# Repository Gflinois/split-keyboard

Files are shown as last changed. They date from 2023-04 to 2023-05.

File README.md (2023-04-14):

# Split-keyboard

This Git project contains everything that is needed for the construction of split 60 % keyboard. The layout used is a custom one (see layout) base on international qwerty. The project include:

- pcb files of a proof of concept with 4 switches
- pcb files of each of the keyboard sides
- a shopping list for all needed components
- cad, stl and gcode for the case files (gcode for an ender 3 with a probe)
- cad, stl and gcode for the keycaps (gcode for an anycubic proton)
- the driver module to use it on linux
- the driver module to use it on windows

## Layout
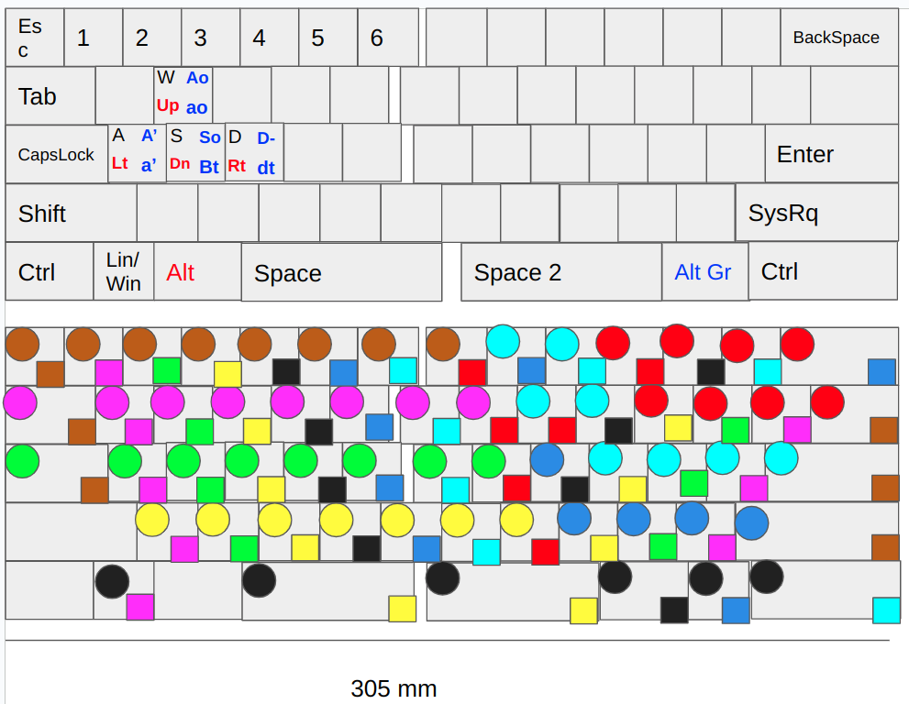
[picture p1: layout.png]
big L mec
 

## Electronic specifiactions

This keyboard is a usb-c teather based one (no battey nor wireless connection provided yet). It is powered by an Atmega 328P stolen on an old arduino nano.

## Contribution

Contributions to this Git project are welcome! Please submit pull requests to the `dev` branch and include a detailed description of your changes.

## License

This project is licensed under the MIT License. See the `LICENSE` file for details.

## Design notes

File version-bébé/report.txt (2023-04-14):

Info: Processing symbol 'R1:Resistor_SMD:R_0805_2012Metric'.
Info: Processing symbol 'C1:Capacitor_SMD:C_0805_2012Metric'.
Info: Processing symbol 'X1:Crystal:Crystal_SMD_SeikoEpson_FA238-4Pin_3.2x2.5mm_HandSoldering'.
Info: Processing symbol 'U1:Package_QFP:TQFP-44_10x10mm_P0.8mm'.
Info: Processing symbol 'SW1:Button_Switch_SMD:SW_SPST_TL3342'.
Info: Processing symbol 'R4:Resistor_SMD:R_0805_2012Metric'.
Info: Processing symbol 'R3:Resistor_SMD:R_0805_2012Metric'.
Info: Processing symbol 'R2:Resistor_SMD:R_0805_2012Metric'.
Info: Processing symbol 'K4:Button_Switch_Keyboard:SW_Matias_1.00u'.
Info: Processing symbol 'K3:Button_Switch_Keyboard:SW_Matias_1.00u'.
Info: Processing symbol 'K2:Button_Switch_Keyboard:SW_Matias_1.00u'.
Info: Processing symbol 'K1:Button_Switch_Keyboard:SW_Matias_1.00u'.
Info: Processing symbol 'D4:keyboard_parts:D_SOD123_axial'.
Info: Processing symbol 'C2:Capacitor_SMD:C_0805_2012Metric'.
Info: Processing symbol 'C3:Capacitor_SMD:C_0805_2012Metric'.
Info: Processing symbol 'C4:Capacitor_SMD:C_0805_2012Metric'.
Info: Processing symbol 'C5:Capacitor_SMD:C_0805_2012Metric'.
Info: Processing symbol 'C6:Capacitor_SMD:C_0805_2012Metric'.
Info: Processing symbol 'C7:Capacitor_SMD:C_0805_2012Metric'.
Info: Processing symbol 'C8:Capacitor_SMD:C_0805_2012Metric'.
Info: Processing symbol 'D1:keyboard_parts:D_SOD123_axial'.
Info: Processing symbol 'D2:keyboard_parts:D_SOD123_axial'.
Info: Processing symbol 'D3:keyboard_parts:D_SOD123_axial'.
Info: Processing symbol 'J1:keyboard_parts:USB_miniB_hirose_5S8'.
Connected U1 pin 28 to unconnected-(U1-Pad28).
Connected U1 pin 16 to Net-(C1-Pad1).
Connected U1 pin 29 to unconnected-(U1-Pad29).
Connected U1 pin 30 to unconnected-(U1-Pad30).
Connected U1 pin 31 to unconnected-(U1-Pad31).
Connected U1 pin 32 to unconnected-(U1-Pad32).
Connected U1 pin 33 to Net-(R2-Pad1).
Connected U1 pin 34 to VUSB.
Connected U1 pin 35 to +5V.
Add net unconnected-(U1-Pad36).
Connected U1 pin 36 to unconnected-(U1-Pad36).
Add net unconnected-(U1-Pad37).
Connected U1 pin 37 to unconnected-(U1-Pad37).
Connected U1 pin 38 to col2.
Connected U1 pin 39 to col1.
Connected U1 pin 40 to row2.
Connected U1 pin 41 to row1.
Add net unconnected-(U1-Pad42).
Connected U1 pin 42 to unconnected-(U1-Pad42).
Connected U1 pin 43 to +5V.
Connected U1 pin 44 to VUSB.
Changed X1 footprint from 'Connector_USB:USB_Micro-B_Amphenol_10104110_Horizontal' to 'Crystal:Crystal_SMD_SeikoEpson_FA238-4Pin_3.2x2.5mm_HandSoldering'.
Connected U1 pin 26 to unconnected-(U1-Pad26).
Changed U1 footprint from 'Crystal:Crystal_SMD_SeikoEpson_FA238-4Pin_3.2x2.5mm_HandSoldering' to 'Package_QFP:TQFP-44_10x10mm_P0.8mm'.
Connected U1 pin 5 to +5V.
Connected U1 pin 6 to Net-(C8-Pad1).
Connected U1 pin 7 to unconnected-(U1-Pad7).
Connected U1 pin 8 to unconnected-(U1-Pad8).
Connected U1 pin 9 to unconnected-(U1-Pad9).
Connected U1 pin 10 to unconnected-(U1-Pad10).
Connected U1 pin 11 to unconnected-(U1-Pad11).
Connected U1 pin 12 to unconnected-(U1-Pad12).
Connected U1 pin 13 to Net-(R1-Pad2).
Connected U1 pin 14 to VUSB.
Connected U1 pin 15 to +5V.
Connected U1 pin 17 to Net-(C2-Pad1).
Connected U1 pin 18 to unconnected-(U1-Pad18).
Connected U1 pin 19 to unconnected-(U1-Pad19).
Connected U1 pin 20 to unconnected-(U1-Pad20).
Connected U1 pin 21 to unconnected-(U1-Pad21).
Connected U1 pin 22 to unconnected-(U1-Pad22).
Connected U1 pin 23 to +5V.
Connected U1 pin 24 to VUSB.
Connected U1 pin 25 to unconnected-(U1-Pad25).
Connected U1 pin 27 to unconnected-(U1-Pad27).
Warning: No net found for symbol X1 pin 4.

Info: Total warnings: 0, errors: 0.

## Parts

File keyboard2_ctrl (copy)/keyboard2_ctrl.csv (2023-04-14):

Source: | /home/etchebest/keyboard/keyboard2_ctrl/keyboard2_ctrl.kicad_sch
Date: | Tue 04 Apr 2023 02:01:32 PM CEST
Tool: | Eeschema 6.0.2+dfsg-1
Generator: | /usr/share/kicad/plugins/bom_csv_grouped_by_value.py
Component Count: | 75
Individual Components:
Item | Qty | Reference(s) | Value | LibPart | Footprint | Datasheet
 |  | 0.1 | C | Device:C | Capacitor_SMD:C_0805_2012Metric | ~
 |  | C1 | 0.1u | Device:C_Small | Capacitor_SMD:C_0805_2012Metric | ~
 |  | C2 | 0.1u | Device:C_Small | Capacitor_SMD:C_0805_2012Metric | ~
 |  | C3 | 0.1u | Device:C_Small | Capacitor_SMD:C_0805_2012Metric | ~
 |  | C4 | 0.1u | Device:C_Small | Capacitor_SMD:C_0805_2012Metric | ~
 |  | C_xi1 | 22p | Device:C_Small | Capacitor_SMD:C_0805_2012Metric | ~
 |  | C_xi2 | 22p | Device:C_Small | Capacitor_SMD:C_0805_2012Metric | ~
 |  | Cerveau1 | ATMEGA32U4 | keyboard_parts:ATMEGA32U4 | Package_QFP:TQFP-44_10x10mm_P0.8mm
 |  | Cglob1 | 4.7u | Device:C_Small | Capacitor_SMD:C_0805_2012Metric | ~
 |  | D_1 | D | Device:D | Capacitor_SMD:C_0805_2012Metric | ~
 |  | D_2 | D | Device:D | Capacitor_SMD:C_0805_2012Metric | ~
 |  | D_3 | D | Device:D | Capacitor_SMD:C_0805_2012Metric | ~
 |  | D_4 | D | Device:D | Capacitor_SMD:C_0805_2012Metric | ~
 |  | D_5 | D | Device:D | Capacitor_SMD:C_0805_2012Metric | ~
 |  | D_6 | D | Device:D | Capacitor_SMD:C_0805_2012Metric | ~
 |  | D_7 | D | Device:D | Capacitor_SMD:C_0805_2012Metric | ~
 |  | D_8 | D | Device:D | Capacitor_SMD:C_0805_2012Metric | ~
 |  | D_9 | D | Device:D | Capacitor_SMD:C_0805_2012Metric | ~
 |  | D_10 | D | Device:D | Capacitor_SMD:C_0805_2012Metric | ~
 |  | D_11 | D | Device:D | Capacitor_SMD:C_0805_2012Metric | ~
 |  | D_12 | D | Device:D | Capacitor_SMD:C_0805_2012Metric | ~
 |  | D_13 | D | Device:D | Capacitor_SMD:C_0805_2012Metric | ~
 |  | D_14 | D | Device:D | Capacitor_SMD:C_0805_2012Metric | ~
 |  | D_15 | D | Device:D | Capacitor_SMD:C_0805_2012Metric | ~
 |  | D_16 | D | Device:D | Capacitor_SMD:C_0805_2012Metric | ~
 |  | D_17 | D | Device:D | Capacitor_SMD:C_0805_2012Metric | ~
 |  | D_18 | D | Device:D | Capacitor_SMD:C_0805_2012Metric | ~
 |  | D_19 | D | Device:D | Capacitor_SMD:C_0805_2012Metric | ~
 |  | D_20 | D | Device:D | Capacitor_SMD:C_0805_2012Metric | ~
 |  | D_21 | D | Device:D | Capacitor_SMD:C_0805_2012Metric | ~
 |  | D_22 | D | Device:D | Capacitor_SMD:C_0805_2012Metric | ~
 |  | D_23 | D | Device:D | Capacitor_SMD:C_0805_2012Metric | ~
 |  | D_24 | D | Device:D | Capacitor_SMD:C_0805_2012Metric | ~
 |  | D_25 | D | Device:D | Capacitor_SMD:C_0805_2012Metric | ~
 |  | D_26 | D | Device:D | Capacitor_SMD:C_0805_2012Metric | ~
 |  | D_27 | D | Device:D | Capacitor_SMD:C_0805_2012Metric | ~
 |  | D_28 | D | Device:D | Capacitor_SMD:C_0805_2012Metric | ~
 |  | D_29 | D | Device:D | Capacitor_SMD:C_0805_2012Metric | ~
 |  | K_1 | KEYSW | keyboard_parts:KEYSW | Button_Switch_Keyboard:SW_Cherry_MX_1.00u_PCB
 |  | K_2 | KEYSW | keyboard_parts:KEYSW | Button_Switch_Keyboard:SW_Cherry_MX_1.00u_PCB
 |  | K_3 | KEYSW | keyboard_parts:KEYSW | Button_Switch_Keyboard:SW_Cherry_MX_1.00u_PCB
 |  | K_4 | KEYSW | keyboard_parts:KEYSW | Button_Switch_Keyboard:SW_Cherry_MX_1.00u_PCB
 |  | K_5 | KEYSW | keyboard_parts:KEYSW | Button_Switch_Keyboard:SW_Cherry_MX_1.00u_PCB
 |  | K_6 | KEYSW | keyboard_parts:KEYSW | Button_Switch_Keyboard:SW_Cherry_MX_1.00u_PCB
 |  | K_A1 | KEYSW | keyboard_parts:KEYSW | Button_Switch_Keyboard:SW_Cherry_MX_1.00u_PCB
 |  | K_Alt1 | KEYSW | keyboard_parts:KEYSW | Button_Switch_Keyboard:SW_Cherry_MX_1.50u_PCB
 |  | K_B1 | KEYSW | keyboard_parts:KEYSW | Button_Switch_Keyboard:SW_Cherry_MX_1.00u_PCB
 |  | K_C1 | KEYSW | keyboard_parts:KEYSW | Button_Switch_Keyboard:SW_Cherry_MX_1.00u_PCB
 |  | K_Caps-Lock1 | KEYSW | keyboard_parts:KEYSW | Button_Switch_Keyboard:SW_Cherry_MX_1.75u_PCB
 |  | K_Ctrl1 | KEYSW | keyboard_parts:KEYSW | Button_Switch_Keyboard:SW_Cherry_MX_1.50u_PCB
 |  | K_D1 | KEYSW | keyboard_parts:KEYSW | Button_Switch_Keyboard:SW_Cherry_MX_1.00u_PCB
 |  | K_E1 | KEYSW | keyboard_parts:KEYSW | Button_Switch_Keyboard:SW_Cherry_MX_1.00u_PCB
 |  | K_Esc1 | KEYSW | keyboard_parts:KEYSW | Button_Switch_Keyboard:SW_Cherry_MX_1.00u_PCB
 |  | K_F1 | KEYSW | keyboard_parts:KEYSW | Button_Switch_Keyboard:SW_Cherry_MX_1.00u_PCB
 |  | K_G1 | KEYSW | keyboard_parts:KEYSW | Button_Switch_Keyboard:SW_Cherry_MX_1.00u_PCB
 |  | K_Lin1 | KEYSW | keyboard_parts:KEYSW | Button_Switch_Keyboard:SW_Cherry_MX_1.00u_PCB
 |  | K_Q1 | KEYSW | keyboard_parts:KEYSW | Button_Switch_Keyboard:SW_Cherry_MX_1.00u_PCB
 |  | K_R1 | KEYSW | keyboard_parts:KEYSW | Button_Switch_Keyboard:SW_Cherry_MX_1.00u_PCB
 |  | K_S1 | KEYSW | keyboard_parts:KEYSW | Button_Switch_Keyboard:SW_Cherry_MX_1.00u_PCB
 |  | K_Shift1 | KEYSW | keyboard_parts:KEYSW | Button_Switch_Keyboard:SW_Cherry_MX_2.25u_PCB
 |  | K_Space1 | KEYSW | keyboard_parts:KEYSW | Button_Switch_Keyboard:SW_Cherry_MX_2.75u_PCB
 |  | K_T1 | KEYSW | keyboard_parts:KEYSW | Button_Switch_Keyboard:SW_Cherry_MX_1.00u_PCB
 |  | K_Tab1 | KEYSW | keyboard_parts:KEYSW | Button_Switch_Keyboard:SW_Cherry_MX_1.50u_PCB
 |  | K_V1 | KEYSW | keyboard_parts:KEYSW | Button_Switch_Keyboard:SW_Cherry_MX_1.00u_PCB
 |  | K_W1 | KEYSW | keyboard_parts:KEYSW | Button_Switch_Keyboard:SW_Cherry_MX_1.00u_PCB
 |  | K_X1 | KEYSW | keyboard_parts:KEYSW | Button_Switch_Keyboard:SW_Cherry_MX_1.00u_PCB
 |  | K_Z1 | KEYSW | keyboard_parts:KEYSW | Button_Switch_Keyboard:SW_Cherry_MX_1.00u_PCB
 |  | pp1 | 16pin_pad | perso_lib:16pin_pad | perso:16pin_pad
 |  | R1 | 10k | Device:R | Resistor_SMD:R_0805_2012Metric | ~
 |  | R_C1 | 220 | Device:R | Resistor_SMD:R_0805_2012Metric | ~
 |  | R_C2 | 220 | Device:R | Resistor_SMD:R_0805_2012Metric | ~
 |  | R_HWB1 | 10k | Device:R | Resistor_SMD:R_0805_2012Metric | ~
 |  | SW1 | SW_PUSH | keyboard_parts:SW_PUSH | Button_Switch_SMD:SW_SPST_TL3342
 |  | USB_C1 | USB_C_Receptacle_USB2.0 | Connector:USB_C_Receptacle_USB2.0 | Connector_USB:USB_C_Receptacle_Amphenol_12401548E4-2A_CircularHoles | https://www.usb.org/sites/default/files/documents/usb_type-c.zip
 |  | xital1 | XTAL_GND | keyboard_parts:XTAL_GND | Crystal:Crystal_SMD_SeikoEpson_TSX3225-4Pin_3.2x2.5mm_HandSoldering
Collated Components:
Item | Qty | Reference(s) | Value | LibPart | Footprint | Datasheet
1 | 1 | 0.1 | C | Device:C | Capacitor_SMD:C_0805_2012Metric | ~
2 | 4 | C1, C2, C3, C4 | 0.1u | Device:C_Small | Capacitor_SMD:C_0805_2012Metric | ~
3 | 2 | C_xi1, C_xi2 | 22p | Device:C_Small | Capacitor_SMD:C_0805_2012Metric | ~
4 | 1 | Cerveau1 | ATMEGA32U4 | keyboard_parts:ATMEGA32U4 | Package_QFP:TQFP-44_10x10mm_P0.8mm
5 | 1 | Cglob1 | 4.7u | Device:C_Small | Capacitor_SMD:C_0805_2012Metric | ~
6 | 29 | D_1, D_2, D_3, D_4, D_5, D_6, D_7, D_8, D_9, D_10, D_11, D_12, D_13, D_14, D_15, D_16, D_17, D_18, D_19, D_20, D_21, D_22, D_23, D_24, D_25, D_26, D_27, D_28, D_29 | D | Device:D | Capacitor_SMD:C_0805_2012Metric | ~
7 | 23 | K_1, K_2, K_3, K_4, K_5, K_6, K_A1, K_B1, K_C1, K_D1, K_E1, K_Esc1, K_F1, K_G1, K_Lin1, K_Q1, K_R1, K_S1, K_T1, K_V1, K_W1, K_X1, K_Z1 | KEYSW | keyboard_parts:KEYSW | Button_Switch_Keyboard:SW_Cherry_MX_1.00u_PCB
8 | 3 | K_Alt1, K_Ctrl1, K_Tab1 | KEYSW | keyboard_parts:KEYSW | Button_Switch_Keyboard:SW_Cherry_MX_1.50u_PCB
9 | 1 | K_Caps-Lock1 | KEYSW | keyboard_parts:KEYSW | Button_Switch_Keyboard:SW_Cherry_MX_1.75u_PCB
10 | 1 | K_Shift1 | KEYSW | keyboard_parts:KEYSW | Button_Switch_Keyboard:SW_Cherry_MX_2.25u_PCB
11 | 1 | K_Space1 | KEYSW | keyboard_parts:KEYSW | Button_Switch_Keyboard:SW_Cherry_MX_2.75u_PCB
12 | 1 | pp1 | 16pin_pad | perso_lib:16pin_pad | perso:16pin_pad
13 | 2 | R1, R_HWB1 | 10k | Device:R | Resistor_SMD:R_0805_2012Metric | ~
14 | 2 | R_C1, R_C2 | 220 | Device:R | Resistor_SMD:R_0805_2012Metric | ~
15 | 1 | SW1 | SW_PUSH | keyboard_parts:SW_PUSH | Button_Switch_SMD:SW_SPST_TL3342
16 | 1 | USB_C1 | USB_C_Receptacle_USB2.0 | Connector:USB_C_Receptacle_USB2.0 | Connector_USB:USB_C_Receptacle_Amphenol_12401548E4-2A_CircularHoles | https://www.usb.org/sites/default/files/documents/usb_type-c.zip
17 | 1 | xital1 | XTAL_GND | keyboard_parts:XTAL_GND | Crystal:Crystal_SMD_SeikoEpson_TSX3225-4Pin_3.2x2.5mm_HandSoldering

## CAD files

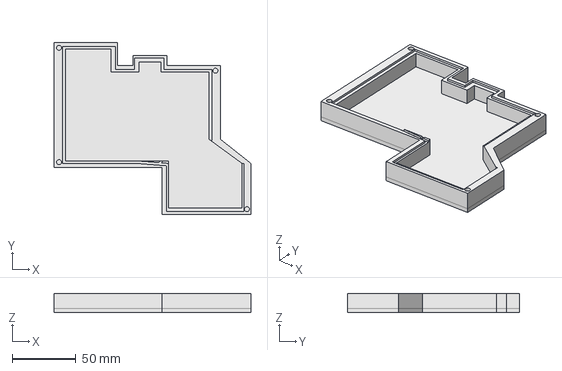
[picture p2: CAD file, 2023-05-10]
cases/ergo V1/case_lower.FCStd
155.0 x 135.0 x 15.0 mm

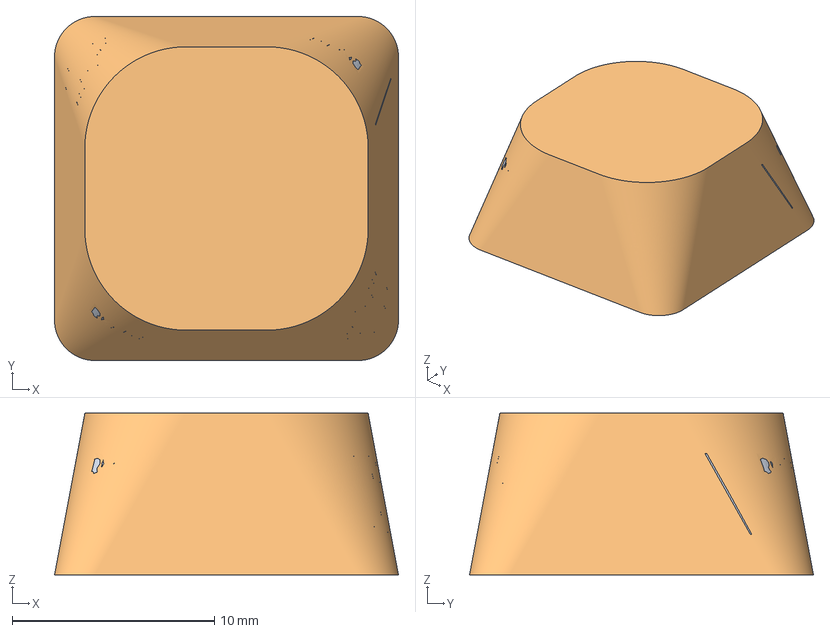
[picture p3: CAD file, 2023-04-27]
keycap-set/1u.FCStd
17.0 x 17.0 x 8.00 mm
PolarPattern (Meshed)

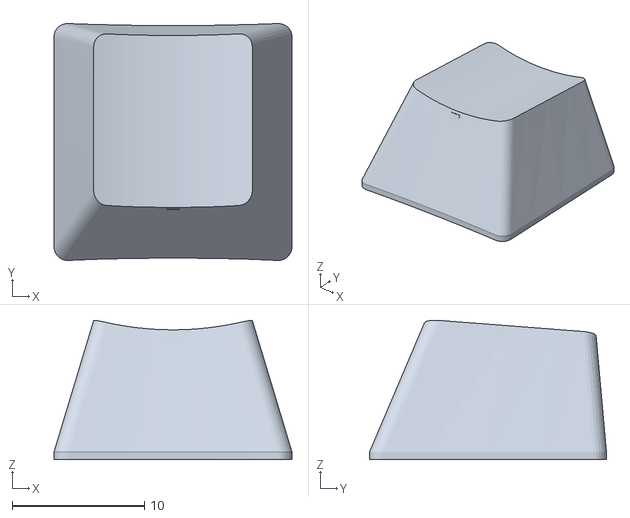
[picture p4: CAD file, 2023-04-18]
keycap-set/not mine/Row 2.stl
18.0 x 17.9 x 10.5

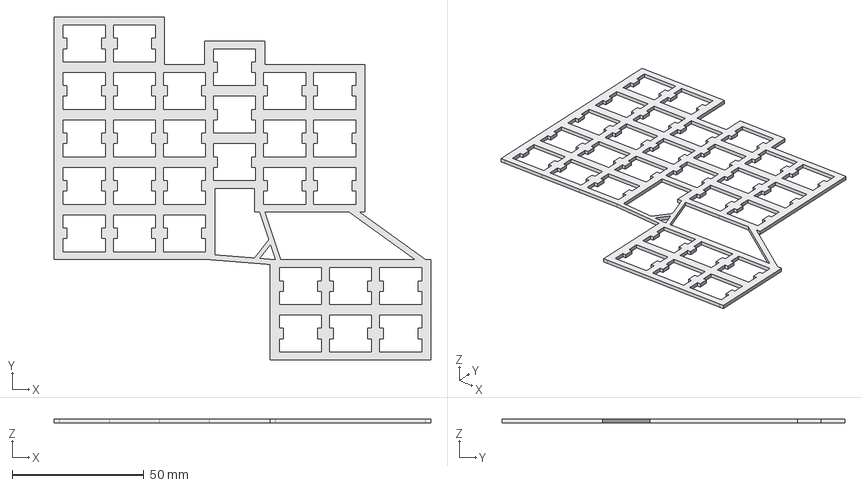
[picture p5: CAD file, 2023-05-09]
cases/ergo V1/plate.FCStd
143.0 x 130.0 x 1.50 mm

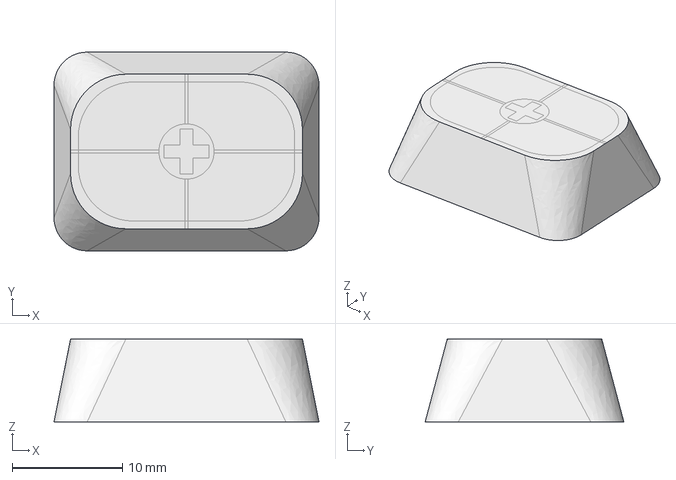
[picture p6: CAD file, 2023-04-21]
keycap-set/1.5u.FCStd
24.0 x 18.0 x 7.50 mm

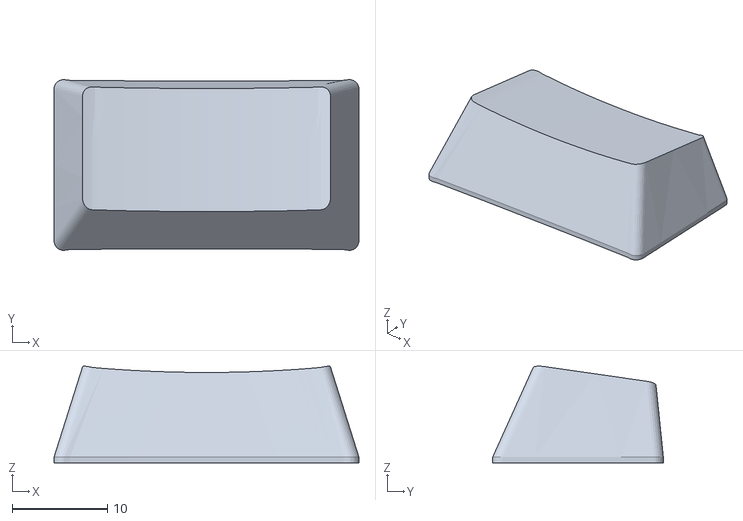
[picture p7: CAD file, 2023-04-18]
keycap-set/not mine/Row 3 Caps LK.stl
32.0 x 17.9 x 10.1

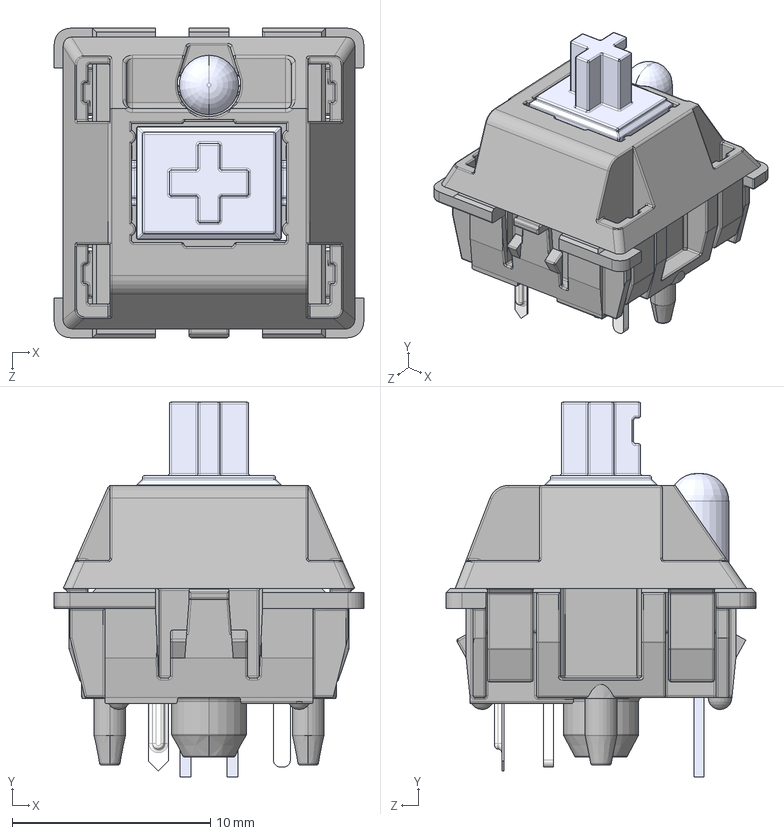
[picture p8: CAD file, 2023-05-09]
cases/ergo V1/MX .STEP
15.6 x 18.9 x 15.6 mm
MX 轴 按键′_ü___¨1
MX 轴 轴体áì_¨￠¨__
MX粣 拸簽LEDLEDLED
MX轴 轴体 底部 μ×2__默认_á2____è_
针脚___默认__è_

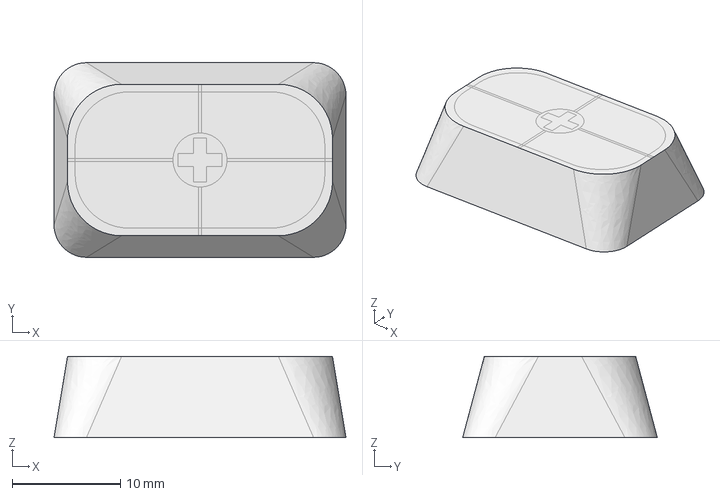
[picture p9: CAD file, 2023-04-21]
keycap-set/1.75.FCStd
27.0 x 18.0 x 7.50 mm

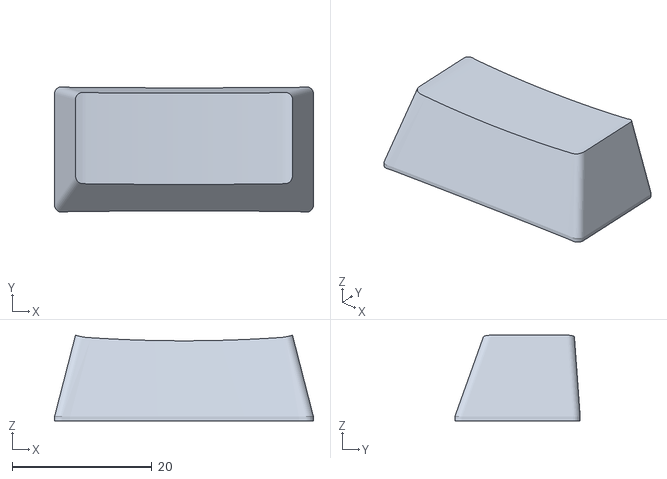
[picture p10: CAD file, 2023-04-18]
keycap-set/not mine/Row 1 Backspace.stl
37.0 x 17.9 x 12.2

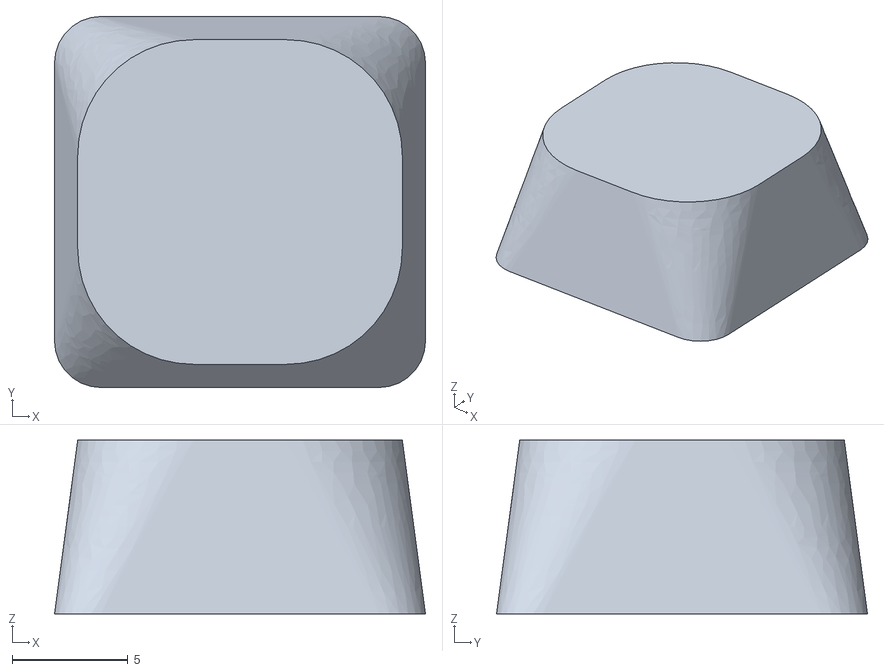
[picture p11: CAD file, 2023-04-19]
keycap-set/1u-maison.stl
16.0 x 16.0 x 7.50

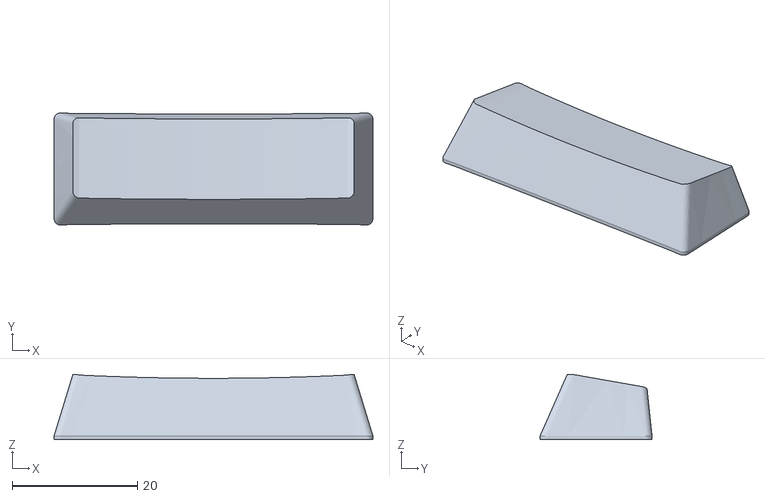
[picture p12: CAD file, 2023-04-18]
keycap-set/not mine/Row 4 Shift R.stl
51.0 x 17.9 x 10.5

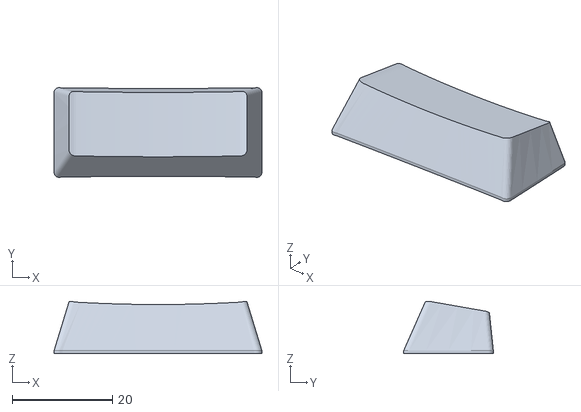
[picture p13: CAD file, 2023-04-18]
keycap-set/not mine/Row 4 Shift L.stl
41.5 x 17.9 x 10.5

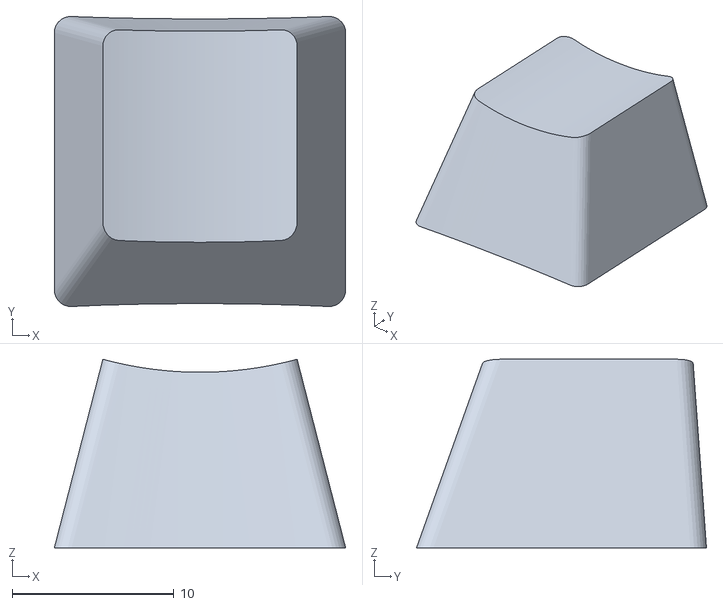
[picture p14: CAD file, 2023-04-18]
keycap-set/not mine/Row 1.stl
18.0 x 17.9 x 11.7

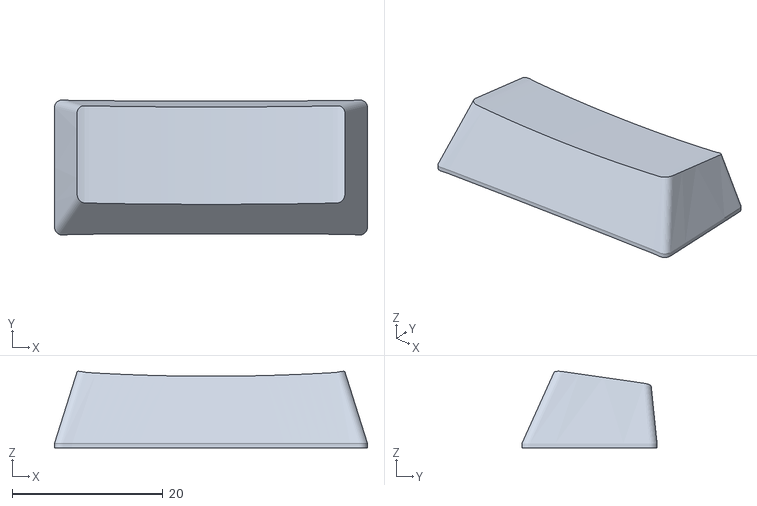
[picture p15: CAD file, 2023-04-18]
keycap-set/not mine/Row 3 Enter.stl
41.5 x 17.9 x 10.1

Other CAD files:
keyboard2_ctrl/keycap_1_U.FCStd
keycap-set/not mine/Row 2 Tab+.stl
keycap-set/not mine/Row 3.stl
keycap-set/not mine/Row 4 Bottom.stl
cases/ergo V1/case_lower.stl
cases/ergo V1/plate.stl
keycap-set/not mine/Row 4 Spacebar.stl
keycap-set/not mine/Row 4.stl

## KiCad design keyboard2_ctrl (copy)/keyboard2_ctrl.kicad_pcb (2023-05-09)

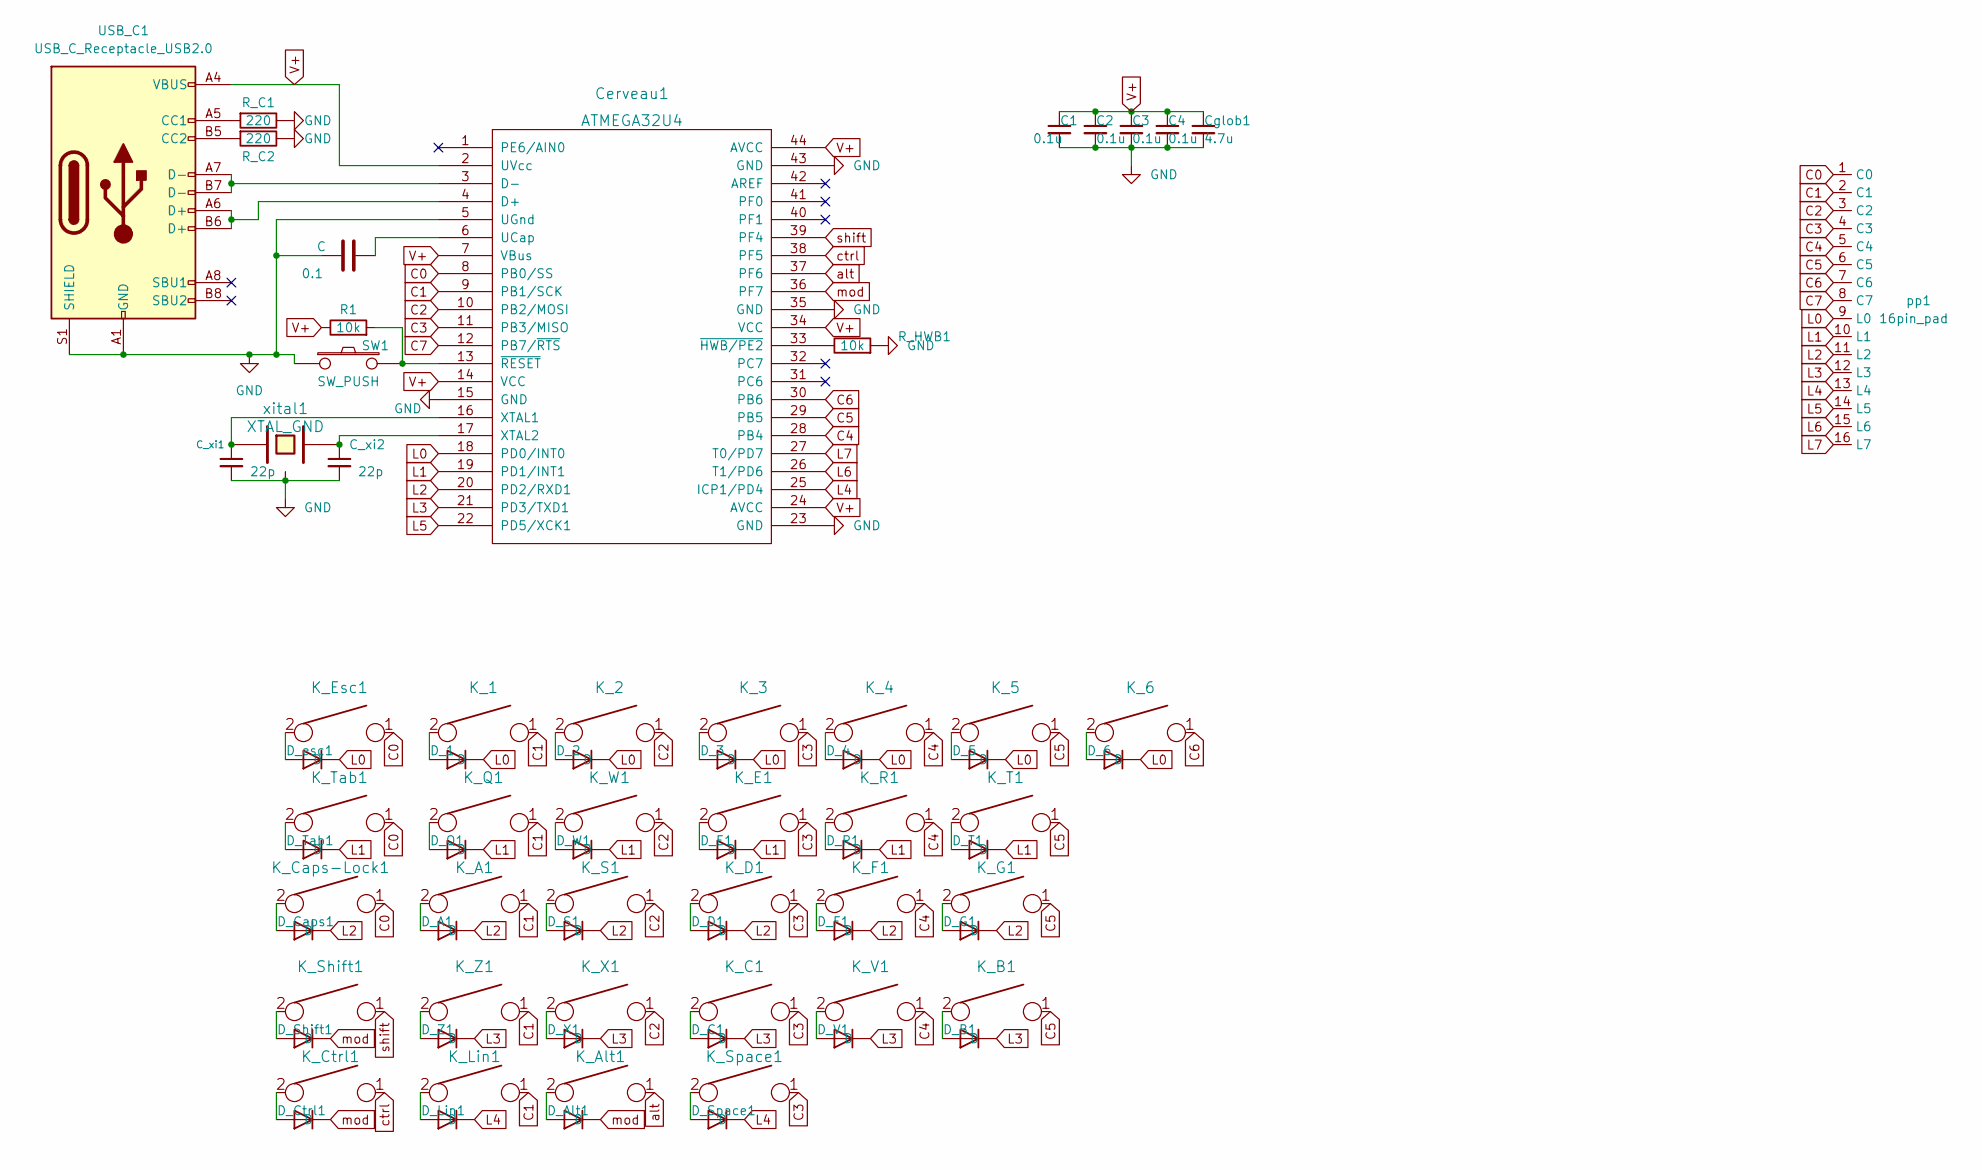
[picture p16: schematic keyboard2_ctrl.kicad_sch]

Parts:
0.1: C; C_0805_2012Metric
C1, C2, C3, C4: 0.1u; C_0805_2012Metric
C_xi1, C_xi2: 22p; C_0805_2012Metric
Cerveau1: ATMEGA32U4; TQFP-44_10x10mm_P0.8mm
Cglob1: 4.7u; C_0805_2012Metric
D_1, D_2, D_3, D_4, D_5, D_6: D; C_0805_2012Metric
D_A1: D; C_0805_2012Metric
D_Alt1: D; C_0805_2012Metric
D_B1: D; C_0805_2012Metric
D_C1: D; C_0805_2012Metric
D_Caps1: D; C_0805_2012Metric
D_Ctrl1: D; C_0805_2012Metric
D_D1: D; C_0805_2012Metric
D_E1: D; C_0805_2012Metric
D_F1: D; C_0805_2012Metric
D_G1: D; C_0805_2012Metric
D_Lin1: D; C_0805_2012Metric
D_Q1: D; C_0805_2012Metric
D_R1: D; C_0805_2012Metric
D_S1: D; C_0805_2012Metric
D_Shift1: D; C_0805_2012Metric
D_Space1: D; C_0805_2012Metric
D_T1: D; C_0805_2012Metric
D_Tab1: D; C_0805_2012Metric
D_V1: D; C_0805_2012Metric
D_W1: D; C_0805_2012Metric
D_X1: D; C_0805_2012Metric
D_Z1: D; C_0805_2012Metric
D_esc1: D; C_0805_2012Metric
K_1, K_2, K_3, K_4, K_5, K_6: KEYSW; SW_Cherry_MX_1.00u_PCB
K_A1: KEYSW; SW_Cherry_MX_1.00u_PCB
K_Alt1: KEYSW; SW_Cherry_MX_1.50u_PCB
K_B1: KEYSW; SW_Cherry_MX_1.00u_PCB
K_C1: KEYSW; SW_Cherry_MX_1.00u_PCB
K_Caps-Lock1: KEYSW; SW_Cherry_MX_1.75u_PCB
K_Ctrl1: KEYSW; SW_Cherry_MX_1.50u_PCB
K_D1: KEYSW; SW_Cherry_MX_1.00u_PCB
K_E1: KEYSW; SW_Cherry_MX_1.00u_PCB
K_Esc1: KEYSW; SW_Cherry_MX_1.00u_PCB
K_F1: KEYSW; SW_Cherry_MX_1.00u_PCB
K_G1: KEYSW; SW_Cherry_MX_1.00u_PCB
K_Lin1: KEYSW; SW_Cherry_MX_1.00u_PCB
K_Q1: KEYSW; SW_Cherry_MX_1.00u_PCB
K_R1: KEYSW; SW_Cherry_MX_1.00u_PCB
K_S1: KEYSW; SW_Cherry_MX_1.00u_PCB
K_Shift1: KEYSW; SW_Cherry_MX_2.25u_PCB
K_Space1: KEYSW; SW_Cherry_MX_2.75u_PCB
K_T1: KEYSW; SW_Cherry_MX_1.00u_PCB
K_Tab1: KEYSW; SW_Cherry_MX_1.50u_PCB
K_V1: KEYSW; SW_Cherry_MX_1.00u_PCB
K_W1: KEYSW; SW_Cherry_MX_1.00u_PCB
K_X1: KEYSW; SW_Cherry_MX_1.00u_PCB
K_Z1: KEYSW; SW_Cherry_MX_1.00u_PCB
R1: 10k; R_0805_2012Metric
R_C1, R_C2: 220; R_0805_2012Metric
R_HWB1: 10k; R_0805_2012Metric
SW1: SW_PUSH; SW_SPST_TL3342
USB_C1: USB_C_Receptacle_USB2.0; USB_C_Receptacle_GCT_USB4085
pp1: 16pin_pad
xital1: XTAL_GND; Crystal_SMD_SeikoEpson_TSX3225-4Pin_3.2x2.5mm_HandSoldering

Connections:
C0: Cerveau1.8 (PB0/SS), K_Caps-Lock1.1, K_Esc1.1, K_Tab1.1, pp1.1 (C0)
C1: Cerveau1.9 (PB1/SCK), K_1.1, K_A1.1, K_Lin1.1, K_Q1.1, K_Z1.1, pp1.2 (C1)
C2: Cerveau1.10 (PB2/MOSI), K_2.1, K_S1.1, K_W1.1, K_X1.1, pp1.3 (C2)
C3: Cerveau1.11 (PB3/MISO), K_3.1, K_C1.1, K_D1.1, K_E1.1, K_Space1.1, pp1.4 (C3)
C4: Cerveau1.28 (PB4), K_4.1, K_F1.1, K_R1.1, K_V1.1, pp1.5 (C4)
C5: Cerveau1.29 (PB5), K_5.1, K_B1.1, K_G1.1, K_T1.1, pp1.6 (C5)
C6: Cerveau1.30 (PB6), K_6.1, pp1.7 (C6)
C7: Cerveau1.12 (PB7/~RTS), pp1.8 (C7)
GND: 0.1.1, C1.2, C2.2, C3.2, C4.2, C_xi1.2, C_xi2.2, Cerveau1.5 (UGnd), Cerveau1.15 (GND), Cerveau1.23 (GND), Cerveau1.35 (GND), Cerveau1.43 (GND), Cglob1.2, R_C1.1, R_C2.1, R_HWB1.2, SW1.1, USB_C1.A1 (GND), USB_C1.A12 (GND), USB_C1.B1 (GND), USB_C1.B12 (GND), USB_C1.S1 (SHIELD), xital1.3
L0: Cerveau1.18 (PD0/INT0), D_1.1 (K), D_2.1 (K), D_3.1 (K), D_4.1 (K), D_5.1 (K), D_6.1 (K), D_esc1.1 (K), pp1.9 (L0)
L1: Cerveau1.19 (PD1/INT1), D_E1.1 (K), D_Q1.1 (K), D_R1.1 (K), D_T1.1 (K), D_Tab1.1 (K), D_W1.1 (K), pp1.10 (L1)
L2: Cerveau1.20 (PD2/RXD1), D_A1.1 (K), D_Caps1.1 (K), D_D1.1 (K), D_F1.1 (K), D_G1.1 (K), D_S1.1 (K), pp1.11 (L2)
L3: Cerveau1.21 (PD3/TXD1), D_B1.1 (K), D_C1.1 (K), D_V1.1 (K), D_X1.1 (K), D_Z1.1 (K), pp1.12 (L3)
L4: Cerveau1.25 (ICP1/PD4), D_Lin1.1 (K), D_Space1.1 (K), pp1.13 (L4)
L5: Cerveau1.22 (PD5/XCK1), pp1.14 (L5)
L6: Cerveau1.26 (T1/PD6), pp1.15 (L6)
L7: Cerveau1.27 (T0/PD7), pp1.16 (L7)
unnamed: 0.1.2, Cerveau1.6 (UCap)
unnamed: C_xi1.1, Cerveau1.16 (XTAL1), xital1.1
unnamed: C_xi2.1, Cerveau1.17 (XTAL2), xital1.2
unnamed: Cerveau1.3 (D-), USB_C1.A7 (D-), USB_C1.B7 (D-)
unnamed: Cerveau1.4 (D+), USB_C1.A6 (D+), USB_C1.B6 (D+)
unnamed: Cerveau1.13 (~RESET), R1.2, SW1.2
unnamed: Cerveau1.33 (~HWB/PE2), R_HWB1.1
unnamed: D_1.2 (A), K_1.2
unnamed: D_2.2 (A), K_2.2
unnamed: D_3.2 (A), K_3.2
unnamed: D_4.2 (A), K_4.2
unnamed: D_5.2 (A), K_5.2
unnamed: D_6.2 (A), K_6.2
unnamed: D_A1.2 (A), K_A1.2
unnamed: D_Alt1.2 (A), K_Alt1.2
unnamed: D_B1.2 (A), K_B1.2
unnamed: D_C1.2 (A), K_C1.2
unnamed: D_Caps1.2 (A), K_Caps-Lock1.2
unnamed: D_Ctrl1.2 (A), K_Ctrl1.2
unnamed: D_D1.2 (A), K_D1.2
unnamed: D_E1.2 (A), K_E1.2
unnamed: D_F1.2 (A), K_F1.2
unnamed: D_G1.2 (A), K_G1.2
unnamed: D_Lin1.2 (A), K_Lin1.2
unnamed: D_Q1.2 (A), K_Q1.2
unnamed: D_R1.2 (A), K_R1.2
unnamed: D_S1.2 (A), K_S1.2
unnamed: D_Shift1.2 (A), K_Shift1.2
unnamed: D_Space1.2 (A), K_Space1.2
unnamed: D_T1.2 (A), K_T1.2
unnamed: D_Tab1.2 (A), K_Tab1.2
unnamed: D_V1.2 (A), K_V1.2
unnamed: D_W1.2 (A), K_W1.2
unnamed: D_X1.2 (A), K_X1.2
unnamed: D_Z1.2 (A), K_Z1.2
unnamed: D_esc1.2 (A), K_Esc1.2
unnamed: R_C1.2, USB_C1.A5 (CC1)
unnamed: R_C2.2, USB_C1.B5 (CC2)
V+: C1.1, C2.1, C3.1, C4.1, Cerveau1.2 (UVcc), Cerveau1.7 (VBus), Cerveau1.14 (VCC), Cerveau1.24 (AVCC), Cerveau1.34 (VCC), Cerveau1.44 (AVCC), Cglob1.1, R1.1, USB_C1.A4 (VBUS), USB_C1.A9 (VBUS), USB_C1.B4 (VBUS), USB_C1.B9 (VBUS)
alt: Cerveau1.37 (PF6), K_Alt1.1
ctrl: Cerveau1.38 (PF5), K_Ctrl1.1
mod: Cerveau1.36 (PF7), D_Alt1.1 (K), D_Ctrl1.1 (K), D_Shift1.1 (K)
shift: Cerveau1.39 (PF4), K_Shift1.1

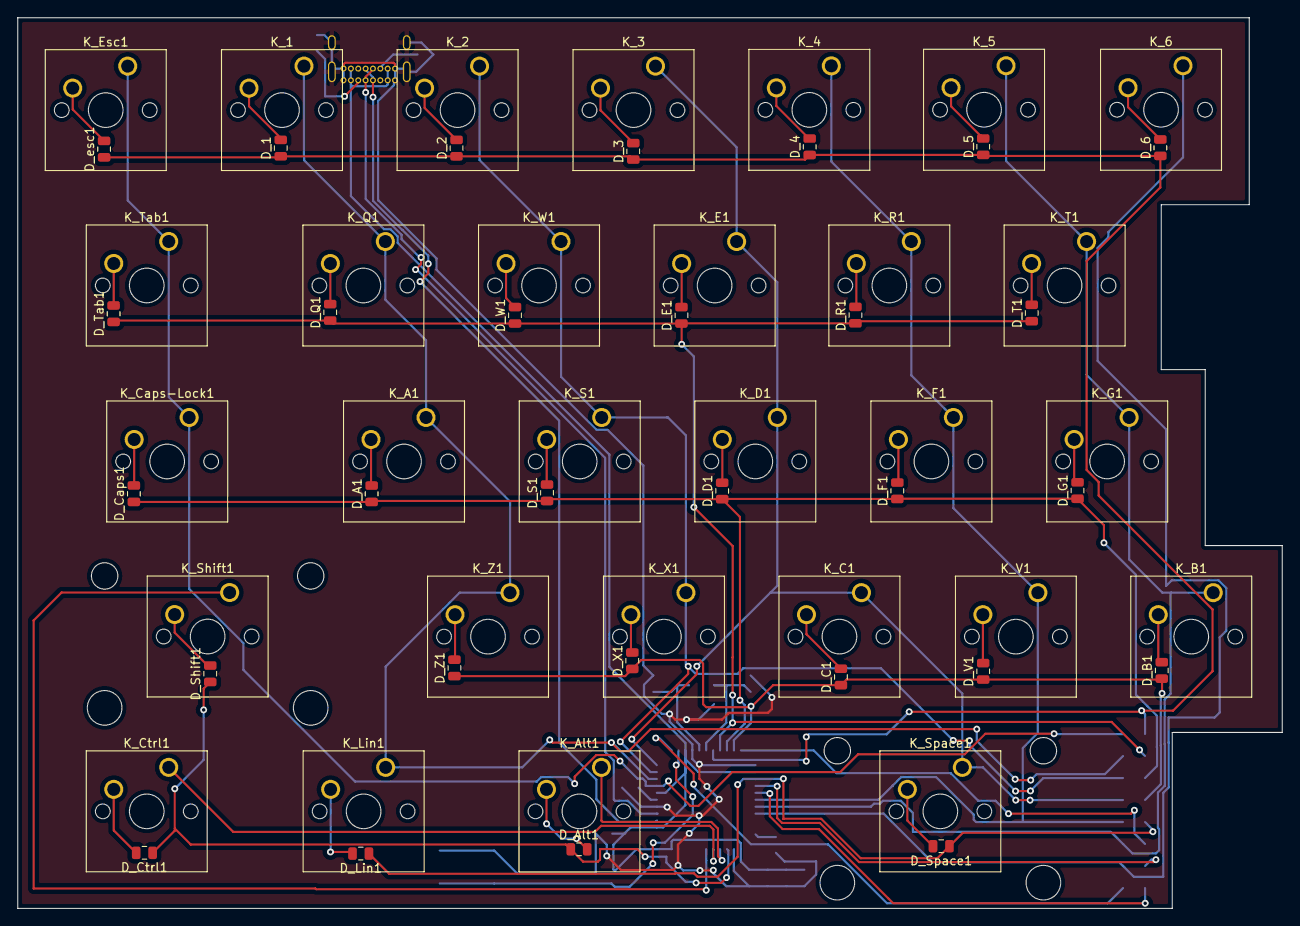
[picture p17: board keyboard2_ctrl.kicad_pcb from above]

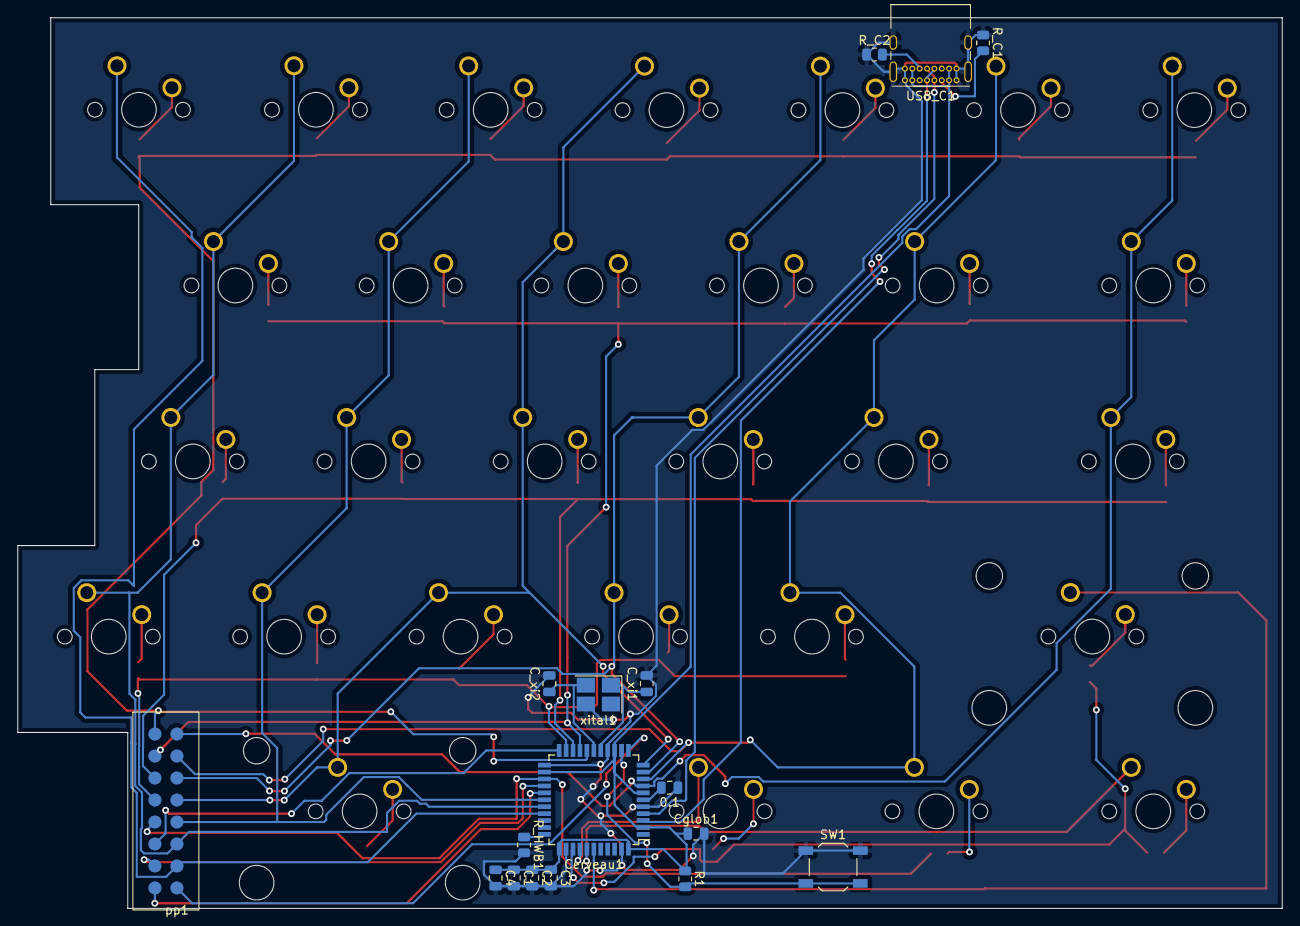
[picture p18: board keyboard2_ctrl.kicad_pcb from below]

Board: 2 copper layers, 146.1 x 102.9 mm, 75 parts (17 on the bottom side), 60 nets.

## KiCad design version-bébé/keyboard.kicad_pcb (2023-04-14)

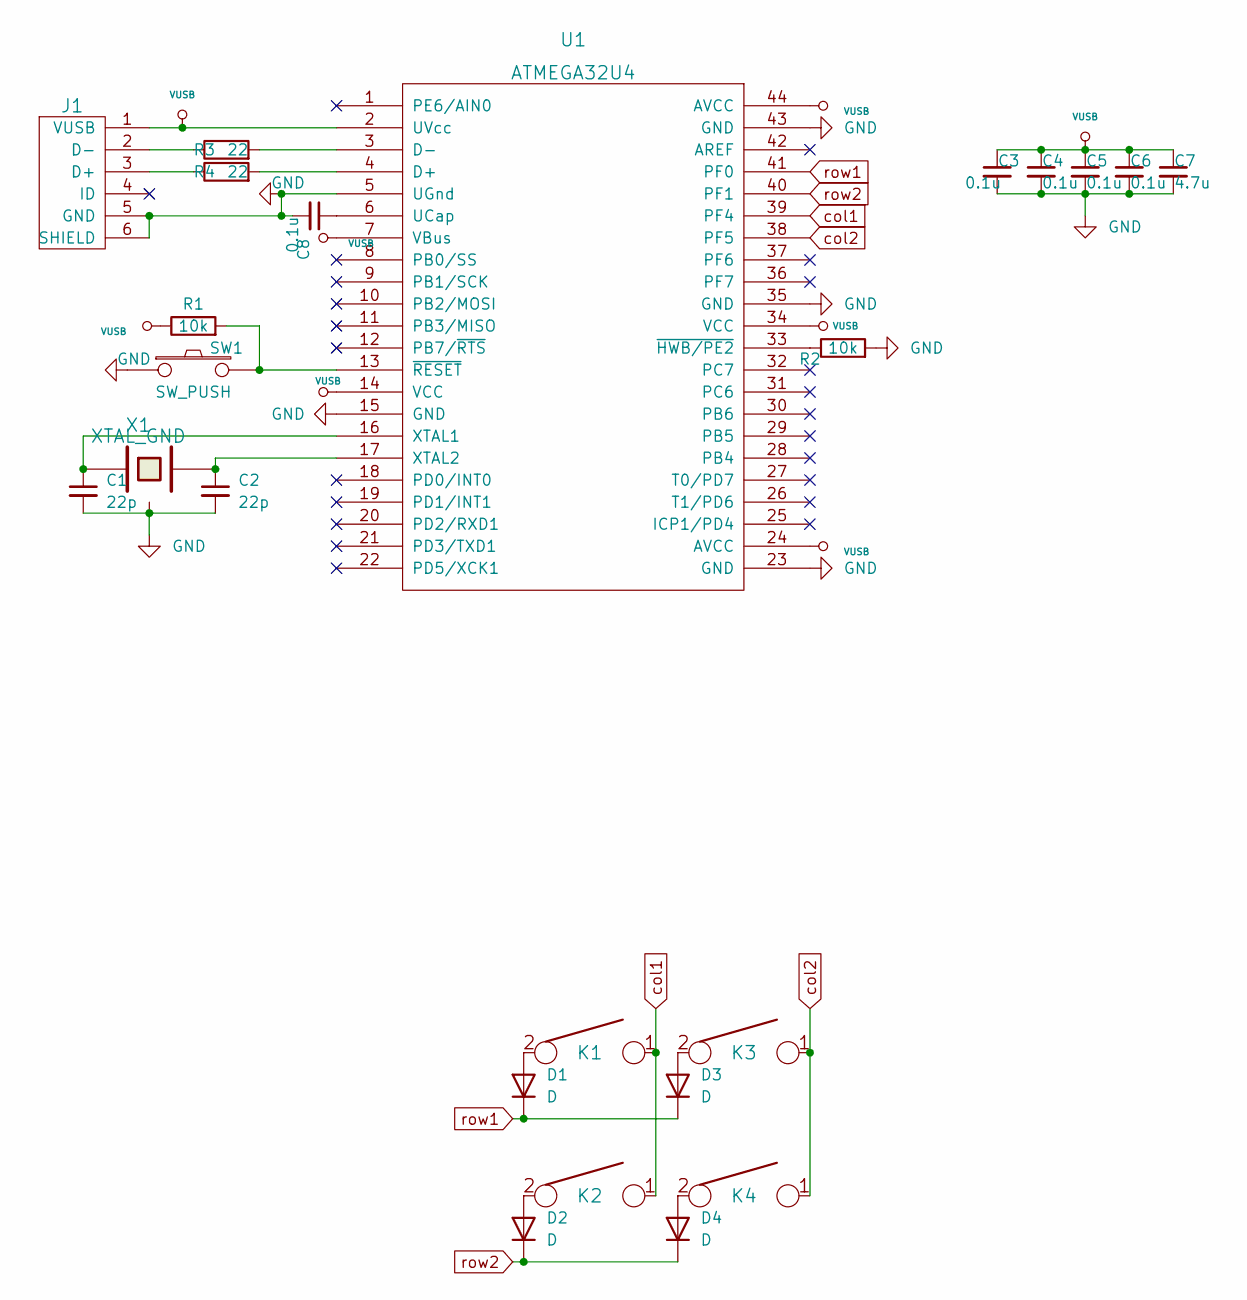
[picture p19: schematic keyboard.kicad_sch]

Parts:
C1, C2: 22p; C_0805_2012Metric
C3, C4, C5, C6, C8: 0.1u; C_0805_2012Metric
C7: 4.7u; C_0805_2012Metric
D1, D2, D3, D4: D; D_SOD123_axial
J1: USB_mini_micro_B; USB_miniB_hirose_5S8
K1, K2, K3, K4: KEYSW; SW_Matias_1.00u
R1, R2: 10k; R_0805_2012Metric
R3, R4: 22; R_0805_2012Metric
SW1: SW_PUSH; SW_SPST_TL3342
U1: ATMEGA32U4; TQFP-44_10x10mm_P0.8mm
X1: XTAL_GND; Crystal_SMD_SeikoEpson_TSX3225-4Pin_3.2x2.5mm_HandSoldering

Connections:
GND: C1.2, C2.2, C3.2, C4.2, C5.2, C6.2, C7.2, C8.2, J1.5 (GND), J1.6 (SHIELD), R2.2, SW1.1, U1.5 (UGnd), U1.15 (GND), U1.23 (GND), U1.35 (GND), U1.43 (GND), X1.3
unnamed: C1.1, U1.16 (XTAL1), X1.1
unnamed: C2.1, U1.17 (XTAL2), X1.2
unnamed: C8.1, U1.6 (UCap)
unnamed: D1.2 (A), K1.2
unnamed: D2.2 (A), K2.2
unnamed: D3.2 (A), K3.2
unnamed: D4.2 (A), K4.2
unnamed: J1.2 (D-), R3.1
unnamed: J1.3 (D+), R4.1
unnamed: R1.2, SW1.2, U1.13 (~RESET)
unnamed: R2.1, U1.33 (~HWB/PE2)
unnamed: R3.2, U1.3 (D-)
unnamed: R4.2, U1.4 (D+)
VUSB: C3.1, C4.1, C5.1, C6.1, C7.1, J1.1 (VUSB), R1.1, U1.2 (UVcc), U1.14 (VCC), U1.24 (AVCC), U1.34 (VCC), U1.44 (AVCC)
col1: K1.1, K2.1, U1.39 (PF4)
col2: K3.1, K4.1, U1.38 (PF5)
row1: D1.1 (K), D3.1 (K), U1.41 (PF0)
row2: D2.1 (K), D4.1 (K), U1.40 (PF1)

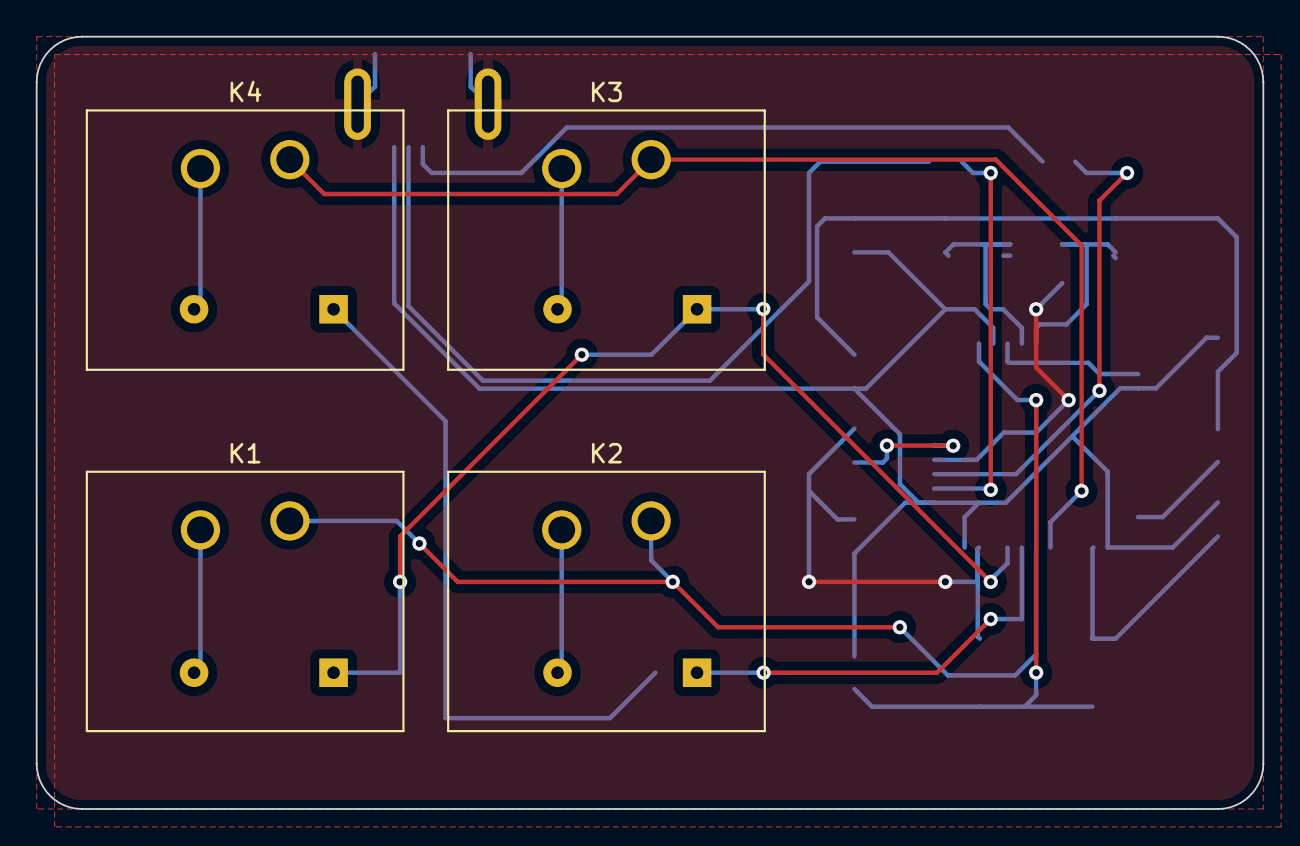
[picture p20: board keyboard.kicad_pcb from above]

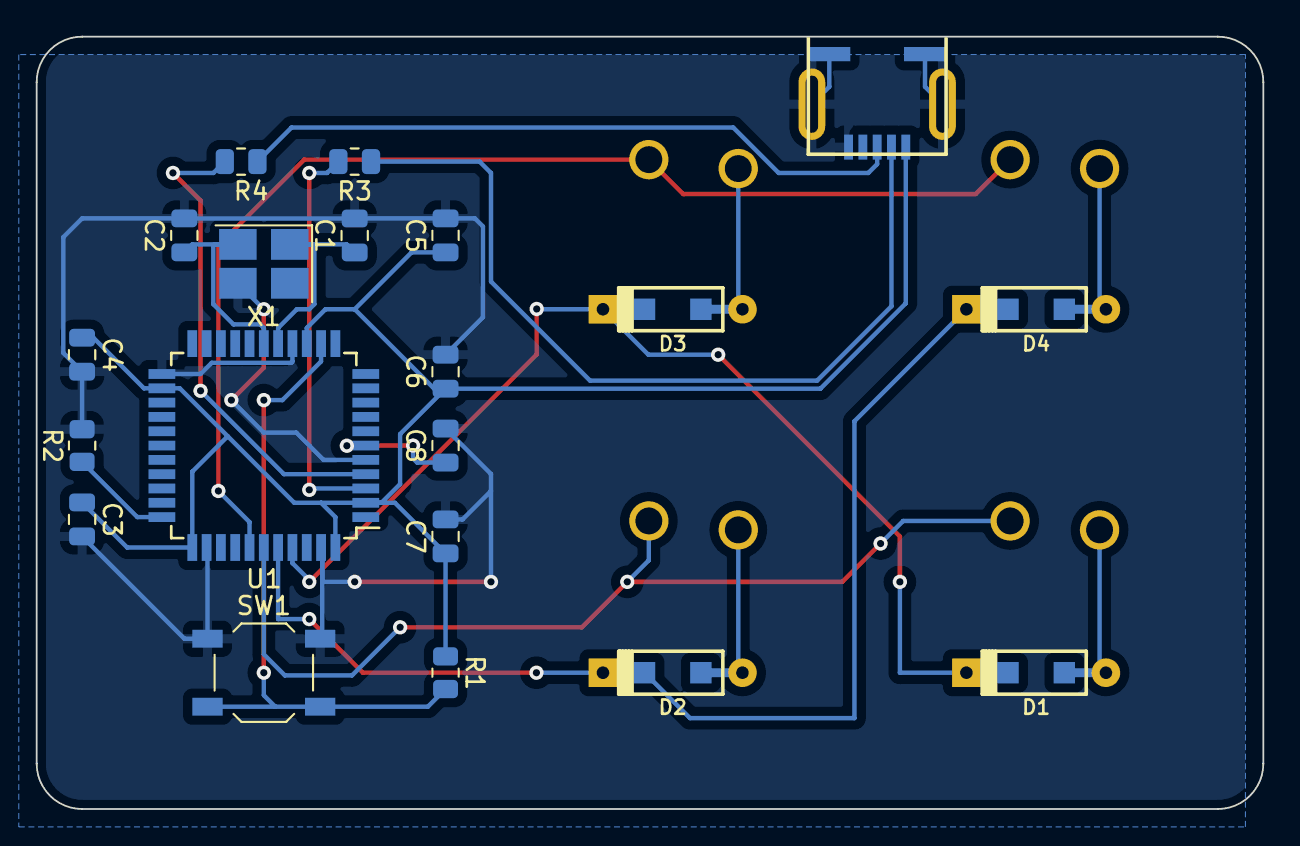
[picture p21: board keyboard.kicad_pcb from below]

Board: 2 copper layers, 68.6 x 43.2 mm, 24 parts (20 on the bottom side), 19 nets.

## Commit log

2023-04-14 bonjour git
    [keyboard.kicad_pcb, keyboard.kicad_sch, keyboard2_ctrl.csv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]
2023-04-14 askip il faut dire ce que c'est un projet ducoup voilà
    [keyboard.kicad_pcb, keyboard.kicad_sch]
2023-04-18 jsplus en vrai lol
    [Row 1 Backspace.stl, Row 1.stl, Row 2 Tab+.stl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]
2023-04-19 ajout de mon keycap perso, test d'impression dans la journée pour le résultat
    [1u-maison.stl, 1u.FCStd]
2023-04-21 nouvelles tailles de keycaps perso
    [1.5u.FCStd, 1.75.FCStd, Row 1 Backspace.stl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]
2023-04-27 v2 des touches
    [1u.FCStd]
2023-05-09 the right keycaps, begining work on the ergo case
    [MX .STEP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]
2023-05-09 v2 plate & début lower case
    [case_lower.FCStd, plate.FCStd, plate.stl]
2023-05-10 update assemblage et lower case
    [case_lower.FCStd, case_lower.stl]
